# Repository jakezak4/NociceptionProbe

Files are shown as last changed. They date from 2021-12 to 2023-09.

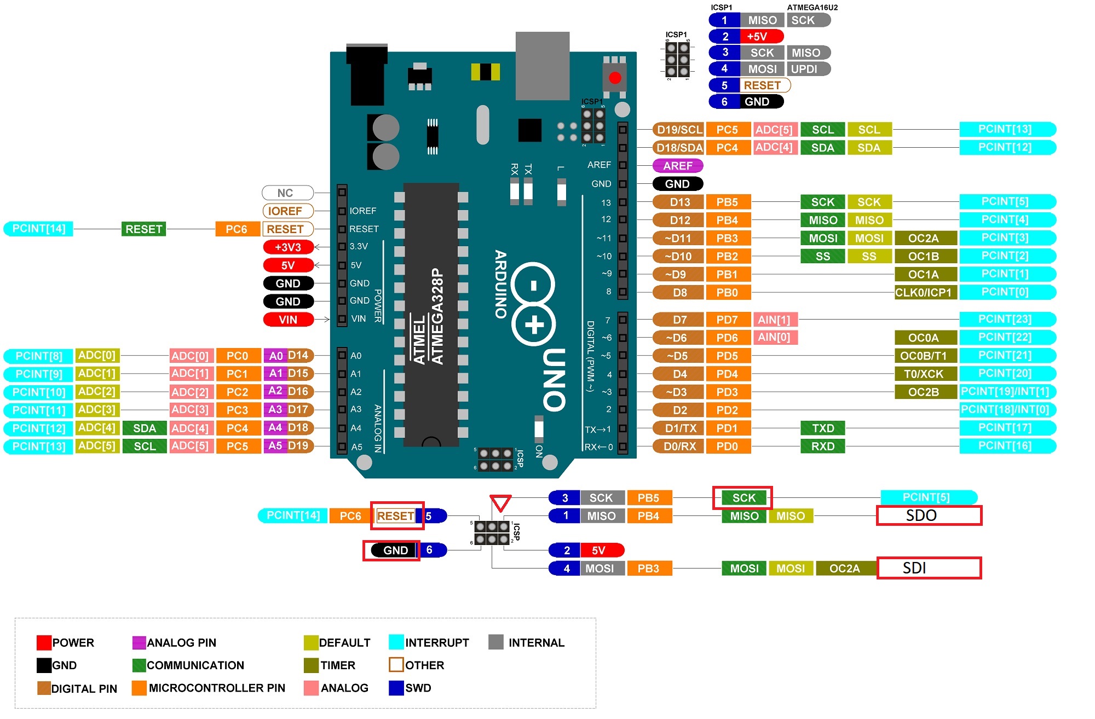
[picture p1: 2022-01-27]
MAX31856_serial_interface.jpg

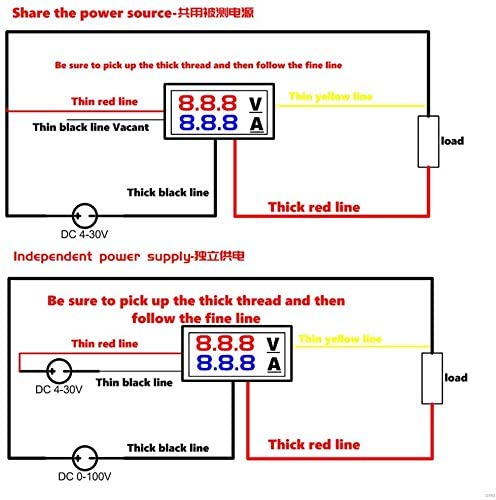
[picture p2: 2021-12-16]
HiLetgo_‎3-01-1407.jpg

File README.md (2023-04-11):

# Nociception Probe with Magnet Wire
Probe system for assaying nociception in Drosophila.  
Designed by Jacob Jaszczak and Luke Breuer  
Built by Jacob Jaszczak

*Installation and Startup* 

1) Install Arduino IDE 
https://www.arduino.cc/en/software

2) Install microcontroler driver. The board URC10 uses CH340G USB to UART converter. Download Windows driver here (copy-paste link): http://sparks.gogo.co.nz/assets/_site_/downloads/CH34x_Install_Windows_v3_4.zip  
For MAC and Linux, see URC10 Cytron manual. 

3) Download and copy files in thermocouple libraries to the Arduino libraries folder as subfolder "PWFusion_MAX31856"  
	2A: Create folder "PWFusion_MAX31856" in "libraries" directory  
	
	2B: path example: ...\Documents\Arduino\libraries\PWFusion_MAX31856
	
	2C: Add the 4 files starting with "PlayingWithFusion_" to the subfolder 

4) Download and move NociceptionProbe.ino file to Arduino folder as subfolder "NociceptionProbe".  
		*note folder name and file name must match.*   
	4A: Create folder "NociceptionProbe" in "Arduino" directory  
	
	4B: path example: ...\Documents\Arduino\thermal_degeneration\thermal_degeneration.ino  
	
	4C: Open "NociceptionProbe.ino" in Arduino IDE 

5) Set up IDE  
	4A: Tools > Board > select "Arduino Uno"
	
	4B: Tools > Port > select port that is activated by the USB connection.
						*If port does not appear, or IDE cannot connect to the board during upload, then trouble shoot through Windows Device Manager*

	4C: Tools > Serial Monitor > Baud > select "38400"
	
	4D: Tools > Manage Libraries > PID by Brett Beauregard 1.2.0 > Install

6) Set program parameters in the "Assay variables" section of code. *note, time variables must be in seconds
  - targetTemp = target temperature that program is held at. 
  - beginningHold = seconds after start button is pressed before the thermal program begins.
  - holdTarget = seconds that the target temperature is held for. After hold time is complete the Peltiers will turn off, but he fans and the thermocouples will stay on. 
  - assayTime = total assay time, afterwhich the fans will shutdown and the thermocouples will stop recording.  
  	-Total assay time needs to include beginningHold + ramp time + holdTarget + any extra for equilibrating to room temp. 
  
7) Upload "NociceptionProbe.ino" code to microcontroller (button at top left with arrow). 

8) Open Serial Monitor (Ctrl + Shift + M) to view output or run SerialPlotAndLog. 
              *Note: Serial Monitor and SerialPlotAndLog cannot be run at the same time   

*Running Temperature Treatment Program* 

1) Before running program:  
	1A: open SerialPlotAndLog 
  	1B: reset microcontroller 

2) Press the START button to begin program. The LED will turn on. 

3) To stop program at any time, press the STOP button, which will turn off the magnet wire heating but still read the thermocouples. Or press the RESET button, which will reload the code in the microcontroller and reset all variables.

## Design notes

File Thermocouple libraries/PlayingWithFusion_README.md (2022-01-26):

# PWFusion_MAX31856
SEN-30005-K ISO
SEN-30006-J ISO
SEN-30007-T ISO
SEN-30008-ST ISO

Note: all thermocouple interface types are available for each board variant

Maxim MAX31856 Thermocouple to Digital Converter Arduino Library
Examples provided to interface with SEN-30005, SEN-30006, SEN-30007 and SEN-30008
Product page links:

SEN-30005 (1-ch): <a href="http://www.playingwithfusion.com/productview.php?pdid=58">J-Type Connector</a>, <a href="http://www.playingwithfusion.com/productview.php?pdid=59">K-Type Connector</a>, <a href="http://www.playingwithfusion.com/productview.php?pdid=60">T-Type Connector</a>, <a href="http://www.playingwithfusion.com/productview.php?pdid=57">Screw Terminal Connector</a>
  
SEN-30006 (2-ch): <a href="http://www.playingwithfusion.com/productview.php?pdid=62">J-Type Connector</a>, <a href="http://www.playingwithfusion.com/productview.php?pdid=63">K-Type Connector</a>, <a href="http://www.playingwithfusion.com/productview.php?pdid=64">T-Type Connector</a>, <a href="http://www.playingwithfusion.com/productview.php?pdid=61">Screw Terminal Connector</a>

SEN-30007 (4-ch Arduino Shield): <a href="http://www.playingwithfusion.com/productview.php?pdid=69">J-Type Connector</a>, <a href="http://www.playingwithfusion.com/productview.php?pdid=70">K-Type Connector</a>, <a href="http://www.playingwithfusion.com/productview.php?pdid=71">T-Type Connector</a>, <a href="http://www.playingwithfusion.com/productview.php?pdid=72">Screw Terminal Connector</a>

SEN-30008 (4-ch universal): <a href="http://www.playingwithfusion.com/productview.php?pdid=73">J-Type Connector</a>, <a href="http://www.playingwithfusion.com/productview.php?pdid=74">K-Type Connector</a>, <a href="http://www.playingwithfusion.com/productview.php?pdid=75">T-Type Connector</a>, <a href="http://www.playingwithfusion.com/productview.php?pdid=76">Screw Terminal Connector</a>

Questions? Feel free to <a href="http://www.playingwithfusion.com/contactus.php">contact us!</a>

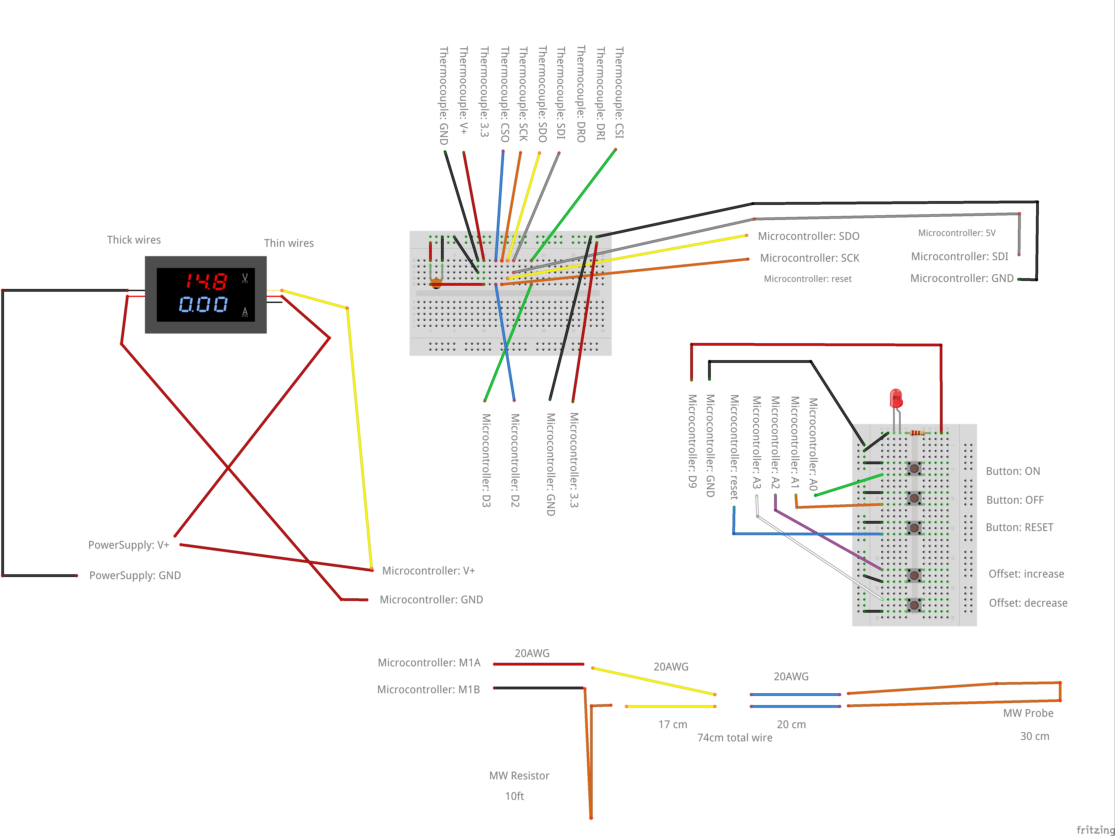
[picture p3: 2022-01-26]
noci_probe_bb.jpg

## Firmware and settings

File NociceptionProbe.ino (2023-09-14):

//PWM magnet wire with two k-type thermalcouples for use as a nociceptive probe

/***************************************************************************
This will heat magnet wire by PWM with two k-type thermalcouples for use as a nociceptive probe
M1 controls PWM  
M2 controls peltiers for assay plate heating
Thermocouple code from PlayingSEN30006_MAX31856_example.ino
***************************************************************************/
#include "PlayingWithFusion_MAX31856.h" //Playing With Fusion thermocouple breakout library 
#include "PlayingWithFusion_MAX31856_STRUCT.h"  //Playing With Fusion thermocouple breakout library 
#include "SPI.h"  //microcontroler library 
#include "PID_v1.h" //v1.2.0 by Brett Beauregard

// ##### Assay variables ###############################################
// #####################################################################
float Probe_targetTemp = 48.0; //target temperature of inside probe 
float Plate_targetTemp = 25.0; //temperature of assay plate
unsigned long assayTime = 4UL*3600000; // 4hrs in milliseconds 
// #####################################################################
// #####################################################################

//PID 1.2.0 by B.B.
//Define Variables we'll be connecting to
double Setpoint_probe, Input_probe, Output_probe, gap_probe;
double Setpoint_plate, Input_plate, Output_plate, gap_plate;

// ##### PID variables ###############################################
//double Kp_probe=24,Ki_probe=4,Kd_probe=5; //6/15
//double Kp_probe=36,Ki_probe=20,Kd_probe=5; //6/10 

double Kp_probe=18,Ki_probe=1,Kd_probe=0; //
//double Kp_plate=100,Ki_plate=10,Kd_plate=0; // old
double Kp_plate=15,Ki_plate=1,Kd_plate=0; // new 

//Specify the links and initial tuning parameters
//P_ON_M specifies that Proportional on Measurement be used, make the output move more smoothly when the setpoint is changed
//P_ON_E (Proportional on Error) is the default behavior
PID myPID_probe(&Input_probe, &Output_probe, &Setpoint_probe, Kp_probe, Ki_probe, Kd_probe,P_ON_M, DIRECT);
PID myPID_plate(&Input_plate, &Output_plate, &Setpoint_plate, Kp_plate, Ki_plate, Kd_plate,P_ON_M, DIRECT);


float probeOffset = 0.0; //changes target temp by 0.5oC
float plateOffset = 0.0; //changes target temp by 0.5oC
float caliProbe_targetTemp = Probe_targetTemp + probeOffset;
float caliPlate_targetTemp = Plate_targetTemp + plateOffset; 
float diffProbeTarget = 0.0;
float diffPlateTarget = 0.0;
int startTimeDelay = 2; //start time delay in minutes 

int PWMmax = 255; //constrain scaling to not burn magnet wire 
int maxCount = 0; //control fast PWM max 
int maxDelay = 0; //control fast PWM max 
float maxCountlength = 0.125; //secs max PWM is held for touch
float maxDelaylength = 20; //secs after touch the max can start again   

int holdingPWM = 0; // Store PWM to hold power for calibration 
bool calibration = false; 
bool enterPWMhold = false;

bool buttonPause = false; //debounce for offset buttons
unsigned long buttonTime = 0L; 

//Playing With Fusion breakout 

uint8_t TC0_CS  = 2;
uint8_t TC1_CS  = 3;

PWF_MAX31856  thermocouple0(TC0_CS);
PWF_MAX31856  thermocouple1(TC1_CS);

//Program variables 
unsigned long startTime; //store time at which the program is started after button click  
float loopCount = 0.0;
unsigned long runInterval = 125; // milliseconds interval of read-PID-print loop 
unsigned long loopMillis; //store last time of loop
int limitWireOutput; // contrained to 0-255 
int limitPeltierOutput;

//Button controler settings 
int sysOnLED = 8; // LED system start

int targetLED = A4; // target gap LED 
int errorLED = A5; // thermocouple error, others too later 

int buttonStart = A0;
int buttonStop = A1;
int offsetUp = A2;
int offsetDown = A3;

int videoPin = 9; //video input from rPi

byte video_record = 0;
bool trigger = false;

//Motor controler settings 
byte M1ArrayPower = 0; //Motor1 Array of Magnet wire 
byte M2ArrayPower = 0; //Motor1 Array of Peltier 

#define URC10_MOTOR_1_DIR 4 // set motor for direction control for Magnet wire
#define URC10_MOTOR_1_PWM 5 // set PWM for power control for Magnet wire

#define URC10_MOTOR_2_DIR 7 // set motor for direction control for Peltier
#define URC10_MOTOR_2_PWM 6 // set PWM for power control for Peltier 

#define COOL 1       // motor current direction for cooling effect 
#define HEAT 0       // motor current direction for heating effect 
    
double tmp0; // thermocouple #1
double tmp1; // thermocouple #2
bool tmpStatus = false; //thermocouple error status 

int tempDirection = HEAT; 

void setup(){
  delay(250);                            // give chip a chance to stabilize
  Serial.begin(115200);                   // set baudrate of serial port
  //Serial.println("Playing With Fusion: MAX31856, SEN-30005;");

  // setup for the the SPI library:
  SPI.begin();                            // begin SPI
  SPI.setClockDivider(SPI_CLOCK_DIV16);   // SPI speed to SPI_CLOCK_DIV16 (1MHz)
  SPI.setDataMode(SPI_MODE3);             // MAX31856 is a MODE3 device
  
  // call config command... options can be seen in the PlayingWithFusion_MAX31856.h file
  thermocouple0.MAX31856_config(K_TYPE, CUTOFF_60HZ, AVG_SEL_4SAMP, CMODE_AUTO);
  thermocouple1.MAX31856_config(K_TYPE, CUTOFF_60HZ, AVG_SEL_4SAMP, CMODE_AUTO);

  pinMode(sysOnLED, OUTPUT); // LED system start
  
  pinMode(targetLED, OUTPUT); // target gap LED 
  pinMode(errorLED, OUTPUT); 
  
  pinMode(buttonStart, INPUT_PULLUP);  
  pinMode(buttonStop, INPUT_PULLUP);
  pinMode(offsetUp, INPUT_PULLUP);
  pinMode(offsetDown, INPUT_PULLUP);
  
  pinMode(videoPin, INPUT); 

  //PID 1.2.0
  //initialize the variables we're linked to
  Setpoint_probe = caliProbe_targetTemp;
  Setpoint_plate = caliPlate_targetTemp;
  //turn the PID on
  myPID_probe.SetMode(AUTOMATIC);   
  myPID_plate.SetMode(AUTOMATIC);
  
  Serial.println("Probe_oC,Plate_oC,diff_Probe,diff_Plate,probeOffset,plateOffset,PWM_probe,PWM_plate,Video");  
}

void loop(){

// ##### Start Button trigger ##############################    
  while (trigger == false){  
    if (trigger == false && digitalRead(buttonStart) == LOW && digitalRead(buttonStop) == HIGH){
      digitalWrite(sysOnLED, HIGH);
      trigger = true;
    } else if (trigger == true && digitalRead(buttonStart) == HIGH && digitalRead(buttonStop) == LOW){
      digitalWrite(sysOnLED, LOW);
      trigger = false;
    }
    delay (1000);
    startTime = millis();  
    loopMillis = millis(); 
  }

// ##### Loop delay ####################################
  if(millis() - loopMillis >= runInterval){ 
    loopMillis = millis(); //store last time of loop
    
  // ##### Thermocouple code ##############################  
    //delay(125); //delay is now happening as while loop //... can be as fast as ~100ms in continuous mode, 1 samp avg
    read_thermocouple(tmp0, tmp1, tmpStatus);
  
  // ################ PWM control ########################################
    //PID 1.2.0
    Setpoint_probe = caliProbe_targetTemp;
    Input_probe = tmp0;
    gap_probe = abs(Setpoint_probe - Input_probe); //distance away from setpoint
  
    Setpoint_plate = caliPlate_targetTemp + 3; //approx degree difference from lights to plate 
    Input_plate = tmp1;
/*
    if(Setpoint_plate - Input_plate >= 0){
      tempDirection = HEAT;
    }else{
      tempDirection = COOL;
    }
*/   
    myPID_probe.SetTunings(Kp_probe, Ki_probe, Kd_probe);
    myPID_probe.Compute();

    myPID_plate.SetTunings(Kp_plate, Ki_plate, Kd_plate);
    myPID_plate.Compute();
  
    if(Output_plate > 50) { //constrain scaling for peltier because heating is delayed and because power supply limit for probe  
      limitPeltierOutput = 50; 
    } else if (Output_plate < 0){
      limitPeltierOutput = 0;
    } else {
      limitPeltierOutput = Output_plate;
    }

    // ######### Probe Range control ###############  
    if (gap_probe < 0.1 && (millis() - startTime) > (60000*startTimeDelay)){        
      digitalWrite(targetLED, HIGH); // Target light
    } else {
      digitalWrite(targetLED, LOW);
    } 

    if(Output_probe > PWMmax) { //constrain scaling 
      limitWireOutput = PWMmax; 
    } else if (Output_probe < 0){
      limitWireOutput = 0;
    } else {
      limitWireOutput = Output_probe; 
    }

    if(tmpStatus == true){ // thermocouple faults will shut PWM off of plate and probe
      limitPeltierOutput = 0;
      limitWireOutput = 0;
    }

    digitalWrite(URC10_MOTOR_1_DIR, 1); //Board motor controler current direction for magnet wire
    M1ArrayPower = (byte) limitWireOutput;  //set PWM byte from polynomial scaling 
    analogWrite(URC10_MOTOR_1_PWM, M1ArrayPower);   //send PWM value to magnet wire
      
    digitalWrite(URC10_MOTOR_2_DIR, tempDirection);
    M2ArrayPower = (byte) limitPeltierOutput;  //set PWM byte from polynomial scaling 
    analogWrite(URC10_MOTOR_2_PWM, M2ArrayPower);   //send PWM value to Peltier   

  // ################ Print variables ########################################
  
    diffProbeTarget = (caliProbe_targetTemp-tmp0);
    diffPlateTarget = (caliPlate_targetTemp-tmp1);
    
    Serial.print(tmp0); // print temperature sensor probe 
    Serial.print(",");
    Serial.print(tmp1); // print temperature sensor plate
    Serial.print(",");
    Serial.print(diffProbeTarget);
    Serial.print(","); 
    Serial.print(diffPlateTarget);
    Serial.print(","); 
    Serial.print(probeOffset,1);
    Serial.print(",");
    Serial.print(plateOffset,1);
    Serial.print(",");
    Serial.print(M1ArrayPower);
    Serial.print(",");
    Serial.print(M2ArrayPower);
    Serial.print(","); 
    Serial.print(video_record); 

    Serial.println();
  }
// ##### End Loop delay ####################################

// ##### Video sync ####################################
  if (digitalRead(videoPin) == LOW){
    video_record = 0 ;
  } else if (digitalRead(videoPin) == HIGH){
    video_record = 1 ;
  }  

// ################ Assay controls ######################################## 

  if (digitalRead(offsetUp) == LOW && digitalRead(offsetDown) == HIGH && buttonPause == false){
    probeOffset = probeOffset + 0.5;
    caliProbe_targetTemp = Probe_targetTemp + probeOffset;
  } else if (digitalRead(offsetUp) == HIGH && digitalRead(offsetDown) == LOW && buttonPause == false){
    probeOffset = probeOffset - 0.5;
    caliProbe_targetTemp = Probe_targetTemp + probeOffset;
  }

  if (digitalRead(offsetUp) == LOW || digitalRead(offsetDown) == LOW && buttonPause == false){
    buttonTime = millis();
    buttonPause = true; 
  } else if (millis() - buttonTime > 100){
    buttonPause = false; 
  }

 // ################ Auto Shutoff ########################################
  while (millis() - startTime > assayTime){ //end program when assay length is done and hold in loop 
    analogWrite(URC10_MOTOR_1_PWM, 0); //turn wire off 
    analogWrite(URC10_MOTOR_2_PWM, 0); //turn peltier off
    digitalWrite(sysOnLED, LOW);
    Serial.println();
    Serial.print("DONE,");
    delay (2000);
    digitalWrite(sysOnLED, HIGH);
  }
}

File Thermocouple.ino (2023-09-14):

// tmp0 and tmp1 are outputs only
void read_thermocouple(double &tmp0, double &tmp1, bool &tmpStatus)
{
  static struct var_max31856 TC_CH0, TC_CH1;   
  struct var_max31856 *tc_ptr;
  
  // Read CH 0
  tc_ptr = &TC_CH0;                             // set pointer
  thermocouple0.MAX31856_update(tc_ptr);        // Update MAX31856 channel 0
  // Read CH 1
  tc_ptr = &TC_CH1;                             // set pointer
  thermocouple1.MAX31856_update(tc_ptr);        // Update MAX31856 channel 1

// ##### Print thermo information to serial port ##############################

  // Thermocouple channel 0
  if(TC_CH0.status)
  {
    // lots of faults possible at once, technically... handle all 8 of them
    // Faults detected can be masked, please refer to library file to enable faults you want represented
    Serial.println("fault(s) detected");
    Serial.print("Fault List: ");
    if(0x01 & TC_CH0.status){Serial.print("OPEN  ");}
    if(0x02 & TC_CH0.status){Serial.print("Overvolt/Undervolt  ");}
    if(0x04 & TC_CH0.status){Serial.print("TC Low  ");}
    if(0x08 & TC_CH0.status){Serial.print("TC High  ");}
    if(0x10 & TC_CH0.status){Serial.print("CJ Low  ");}
    if(0x20 & TC_CH0.status){Serial.print("CJ High  ");}
    if(0x40 & TC_CH0.status){Serial.print("TC Range  ");}
    if(0x80 & TC_CH0.status){Serial.print("CJ Range  ");}
    Serial.println(" ");
    digitalWrite(errorLED, HIGH);
    tmpStatus = true; 
  }
  else  // no fault, print temperature data
  {
    //Serial.println("no faults detected");
    // MAX31856 Internal Temp
    tmp0 = (double)TC_CH0.ref_jcn_temp * 0.015625;  // convert fixed pt # to double
    //Serial.print("Tint = ");                      // print internal temp heading
    if((-100 > tmp0) || (150 < tmp0)){Serial.println("unknown fault");}
    else{Serial.print("");}
    
    // MAX31856 External (thermocouple) Temp
    tmp0 = (double)TC_CH0.lin_tc_temp * 0.0078125;           // convert fixed pt # to double
  }

  // Thermocouple channel 1
  if(TC_CH1.status)
  {
    // lots of faults possible at once, technically... handle all 8 of them
    // Faults detected can be masked, please refer to library file to enable faults you want represented
    Serial.println("fault(s) detected");
    Serial.print("Fault List: ");
    if(0x01 & TC_CH1.status){Serial.print("OPEN  ");}
    if(0x02 & TC_CH1.status){Serial.print("Overvolt/Undervolt  ");}
    if(0x04 & TC_CH1.status){Serial.print("TC Low  ");}
    if(0x08 & TC_CH1.status){Serial.print("TC High  ");}
    if(0x10 & TC_CH1.status){Serial.print("CJ Low  ");}
    if(0x20 & TC_CH1.status){Serial.print("CJ High  ");}
    if(0x40 & TC_CH1.status){Serial.print("TC Range  ");}
    if(0x80 & TC_CH1.status){Serial.print("CJ Range  ");}
    Serial.println(" ");
    digitalWrite(errorLED, HIGH);
    tmpStatus = true; 
  }
  else  // no fault, print temperature data
  {
    //Serial.println("no faults detected");
    // MAX31856 Internal Temp
    tmp1 = (double)TC_CH1.ref_jcn_temp * 0.015625;  // convert fixed pt # to double
    
    // MAX31856 External (thermocouple) Temp
    tmp1 = (double)TC_CH1.lin_tc_temp * 0.0078125;           // convert fixed pt # to double
  }
  if(!TC_CH0.status & !TC_CH1.status){// no errors 
    //digitalWrite(errorLED, LOW);
    //tmpStatus = false; right now allowing reset while program is running is off. If the TC faults the program needs to be restarted  
  }
}

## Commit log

2019-04-03 Added PWM feedback control
2021-12-13 Update from 20211206
    Update code structure, improve PID control and calibration readout
2021-12-13 Board data sheets
2021-12-14 Breadboard diagram
    [noci_probe.fzz]
2021-12-14 Update power meter
    [noci_probe.fzz]
2021-12-16 Add offset buttons
    Add offset buttons and clarify serial monitor readout
2021-12-16 print with serial plotter compatibility
2021-12-16 Volt Amp meter
2021-12-16 Added offset buttons and probe wires
    [noci_probe.fzz]
2022-01-12 remove 3.3v and extra ground
    Removed 3.3v out connection on thermocouple breakout board. Removed thin wire ground on voltmeter
    [noci_probe.fzz]
2022-01-14 updating serial.print readout
2022-01-14 serial.print formatting for SerialPlotAndLogger
2022-01-26 wiring diagram
2022-01-27 diagram of Arduino Uno serial interface
    The Cytron board uses the same pinout configuration for the ICSP as the Uno board
2022-01-31 offset as half degree increment. fix data format
    [NociceptionProbe.ino]
2022-02-06 PWM print and broad clean up
    Removed time controls leftover from the microscope system
2022-02-07 changed prototype PID code to PID library
    https://playground.arduino.cc/Code/PIDLibraryAdaptiveTuningsExample/
2022-03-28 code used 20220328
    modifications to the conservative PID controller
2022-04-28 Add RPi video sync
    Sync video from RPi to Arduino to be saved with SPAL
2022-05-05 Calibration and probe PWM hold
    Add calibration button control. Add probe PWM button control
2022-05-06 Swap Hold, add readouts
    Swap PWM hold control to Peltier temp control. Add target % plate and plate offset readout
    [NociceptionProbe.ino]
2022-05-07 New PID dynamics
    Add control of start PID vs Assay PID. Make PIDs more reactive.
2022-05-12 PID updates
    PID control updates while testing with larvae
2022-05-18 Used for 5/16 heat test
    used for heat transfer test
2022-05-20 Delete old PID, further tests
    Deleted old PID and replaced with second myPID. Tested P_ON_M vs E. Cleaned some code. Still need to clean more old buttons and functions
    [NociceptionProbe.ino]
2022-06-03 Time fix
    Made delay programable. Made read interval consistent. New bug in SPAL of not responding after >5min run
    [NociceptionProbe.ino]
2023-04-11 Added PID library instruction
    Forgot to add instillation instructions for PID library
